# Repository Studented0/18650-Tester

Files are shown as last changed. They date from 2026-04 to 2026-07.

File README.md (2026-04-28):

# CellScan
 
A 4-channel 18650 battery analyzer. Tests up to 4 cells at once and measures voltage, capacity in mAh, and internal resistance per channel. Results show on a small OLED with a rotary encoder to navigate, and a WiFi dashboard to start and stop tests remotely/edit settings.
 
---
 
## Screenshots
 
Schematic
PCB front
PCB back
---
 
## Why I built this
 
My science fair project was a 3S34P battery pack from 34 salvaged 18650 cells. I bought a cheap tester off Amazon to sort them but I wanted to know how it actually worked. I also wanted an excuse to learn PCB design. CellScan is the result, a two-layer PCB with SMD assembly through JLCPCB.
 
---
 
## Hardware
 
Two-layer board, 100×150mm, designed in KiCad 9. SMD components assembled by JLCPCB. Through-hole parts soldered by hand after the board arrives: four MOSFETs, four cement resistors, four cell holders, the OLED header, the ESP32 dev board, and the rotary encoder. The cement resistors run hot under load so they sit raised slightly off the board.
 
Each channel has an INA219 current sensor, an IRLZ44N MOSFET as a discharge switch, and a 1Ω 10W cement resistor as the load. All four INA219s share an I2C bus through a TCA9548A multiplexer since they would otherwise have the same address. Each channel also has a TP4056 lithium charger for charging and discharging. 
 
---
 
## How it measures
 
**Voltage** — INA219 reads bus voltage continuously on each channel.
 
**Capacity** — ESP32 switches the MOSFET on to start discharge. Capacity accumulates by coulomb counting every 500ms until the cell hits the cutoff voltage.
 
`mAh += current_mA * (elapsed_ms / 3600000.0)`
 
**Internal resistance (DCIR)** — Measured at test start using voltage sag. MOSFET off, read open-circuit voltage. MOSFET on, wait 100ms, read loaded voltage and current.
 
`ESR (mΩ) = (V_oc - V_load) / I_load * 1000`
 
---
 
## Rotary Encoder
 
EC11 encoder wired directly to the ESP32. Rotate to switch between channels, press to open a menu, long press to go back. From the menu you can start a test, stop it, or adjust the cutoff voltage per channel. 
 
### Wiring
 
| Signal | GPIO |
|---|---|
| ENC_A | 15 |
| ENC_B | 2 |
| ENC_SW | 5 |
| SDA | 21 |
| SCL | 22 |
 
---
 
## Firmware
 
`firmware/CellScan.ino` — state machine per channel, coulomb counting, DCIR measurement, TP4056 CE control, rotary encoder UI, OLED display, WiFi dashboard.
 
Libraries needed: Adafruit INA219, Adafruit SSD1306, Adafruit GFX, ArduinoJson. Install through Arduino IDE library manager. Board: ESP32 Dev Module.
 
---
 
## Bill of Materials
 
SMD parts ordered through JLCPCB assembly. Through-hole parts sourced separately.
 
| Component | Qty | LCSC | Note |
|---|-----|---|---|
| 100nF 0402 cap | 11 | C1525 | Basic |
| 10kΩ 0402 resistor | 7 | C25744 | Basic |
| 5.1kΩ 0402 resistor | 2 | C25905 | Basic — USB-C CC pull-downs |
| 1.2kΩ 0402 resistor | 4 | C25862 | Extended — TP4056 PROG |
| 1kΩ 0402 resistor | 8 | C11702 | Basic — LED series |
| Red LED 0402 | 8 | C71911 | Extended |
| INA219AIDR | 4 | C138706 | Extended |
| TCA9548AMRGER | 1 | C2876717 | Extended |
| TP4056 SOP-8 | 4 | C16581 | Extended |
| GCT USB4125 USB-C | 1 | C2682777 | Extended |
 
| Component | Qty | Link |
|---|-----|---|
| ESP32 WROOM-32 dev board | 1 | [Amazon](https://www.amazon.com/dp/B08D5ZD528) |
| IRLZ44N MOSFET | 4 | [Amazon](https://www.amazon.com/Technologies-Threshold-Protective-Packaging-IRLZ44NPBF/dp/B0FMQCYG6Q/) |
| 1Ω 10W cement resistor | 4 | [Amazon](https://www.amazon.com/Resistors-Wirewound-Resistance-Precharge-Horizontal/dp/B09V5MTX8Q/) |
| 18650 cell holders | 4 | [Amazon](https://www.amazon.com/Battery-Storage-Holder-Button-Single/dp/B07KD9JLH3/) |
| SSD1306 OLED 0.96" | 1 | [Amazon](https://www.amazon.com/UCTRONICS-SSD1306-Self-Luminous-Display-Raspberry/dp/B072Q2X2LL/) |
| EC11 rotary encoder | 1 | already owned |
 
---
 
## Repository Structure
 
```
18650-Tester/
├── BOM.csv
├── README.md
├── firmware/
│   └── CellScan.ino
└── hardware/
    ├── CellScan_Schematic.kicad_sch
    ├── CellScan_Schematic.kicad_pcb
    ├── CellScan_Schematic.kicad_pro
    ├── CellScan_Schematic.pdf
    ├── libraries/
    │   └── ESP32-DevKitC-30PIN.kicad_mod
    └── gerbers/
```
 
---
 
## License
 
[MIT](LICENSE)

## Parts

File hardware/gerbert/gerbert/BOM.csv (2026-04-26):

Comment | Designator | Footprint | Quantity | LCSC Part | Note
100nF | BAT1.3 BAT1.4 BAT2.3 BAT2.4 BAT3.3 BAT3.4 BAT4.3 BAT4.4 ENCC1 ENCC2 ENCC3 | C_0402_1005Metric | 11 | C1525 | Basic
10k | BAT1.1 BAT2.1 BAT3.1 BAT4.1 ENCR1 ENCR2 ENCR3 | R_0402_1005Metric | 7 | C25744 | Basic
5.1k | R5 R6 | R_0402_1005Metric | 2 | C25905 | Basic — CC1/CC2 USB-C pull-downs
1.2k | BAT1.2 BAT2.2 BAT3.2 BAT4.2 | R_0402_1005Metric | 4 | C25862 | Extended — TP4056 PROG resistors
1k | BAT1RED1 BAT1GREEN1 BAT2RED1 BAT2GREEN1 BAT3RED1 BAT3GREEN1 BAT4RED1 BAT4GREEN1 | R_0402_1005Metric | 8 | C11702 | Basic — LED series resistors
RED LED 0402 | RED1 RED2 RED3 RED4 GREEN1 GREEN2 GREEN3 GREEN4 | LED_0402_1005Metric | 8 | C71911 | Extended — all indicators use same red LED
INA219AIDR | U3 U4 U5 U6 | SOIC-8_3.9x4.9mm_P1.27mm | 4 | C138706 | Extended
TCA9548AMRGER | U2 | Texas_RGE0024C_VQFN-24-1EP_4x4mm_P0.5mm_EP2.1x2.1mm | 1 | C2876717 | Extended
TP4056-42-ESOP8 | U7 U8 U9 U10 | SOIC-8-1EP_3.9x4.9mm_P1.27mm_EP2.41x3.3mm_ThermalVias | 4 | C16581 | Extended
GCT USB4125 USB-C | J3 | USB_C_Receptacle_GCT_USB4125 | 1 | C2682777 | Extended — dedicated 5V power input
-- THROUGH-HOLE (manual solder) --
IRLZ44N MOSFET | Q1 Q2 Q3 Q4 | TO-220-3_Vertical | 4 |  | Amazon — solder by hand
1ohm 10W resistor | R1 R2 R3 R4 | R_Axial_Power_L48.0mm_W12.5mm_P55.88mm | 4 |  | Amazon — solder by hand
18650 cell holder | BT1 BT2 BT3 BT4 | BatteryHolder_Keystone_1042_1x18650 | 4 |  | Amazon — solder by hand
OLED 4-pin header | J1 | PinHeader_1x04_P2.54mm_Vertical | 1 |  | Amazon — solder by hand
ESP32-WROOM-32 dev board | U1 | ESP32-DevKitC-30PIN | 1 |  | Amazon — socket or solder by hand
EC11 rotary encoder | SW1 | RotaryEncoder_Alps_EC11E-Switch_Vertical_H20mm | 1 |  | JLCPCB PCB — solder by hand

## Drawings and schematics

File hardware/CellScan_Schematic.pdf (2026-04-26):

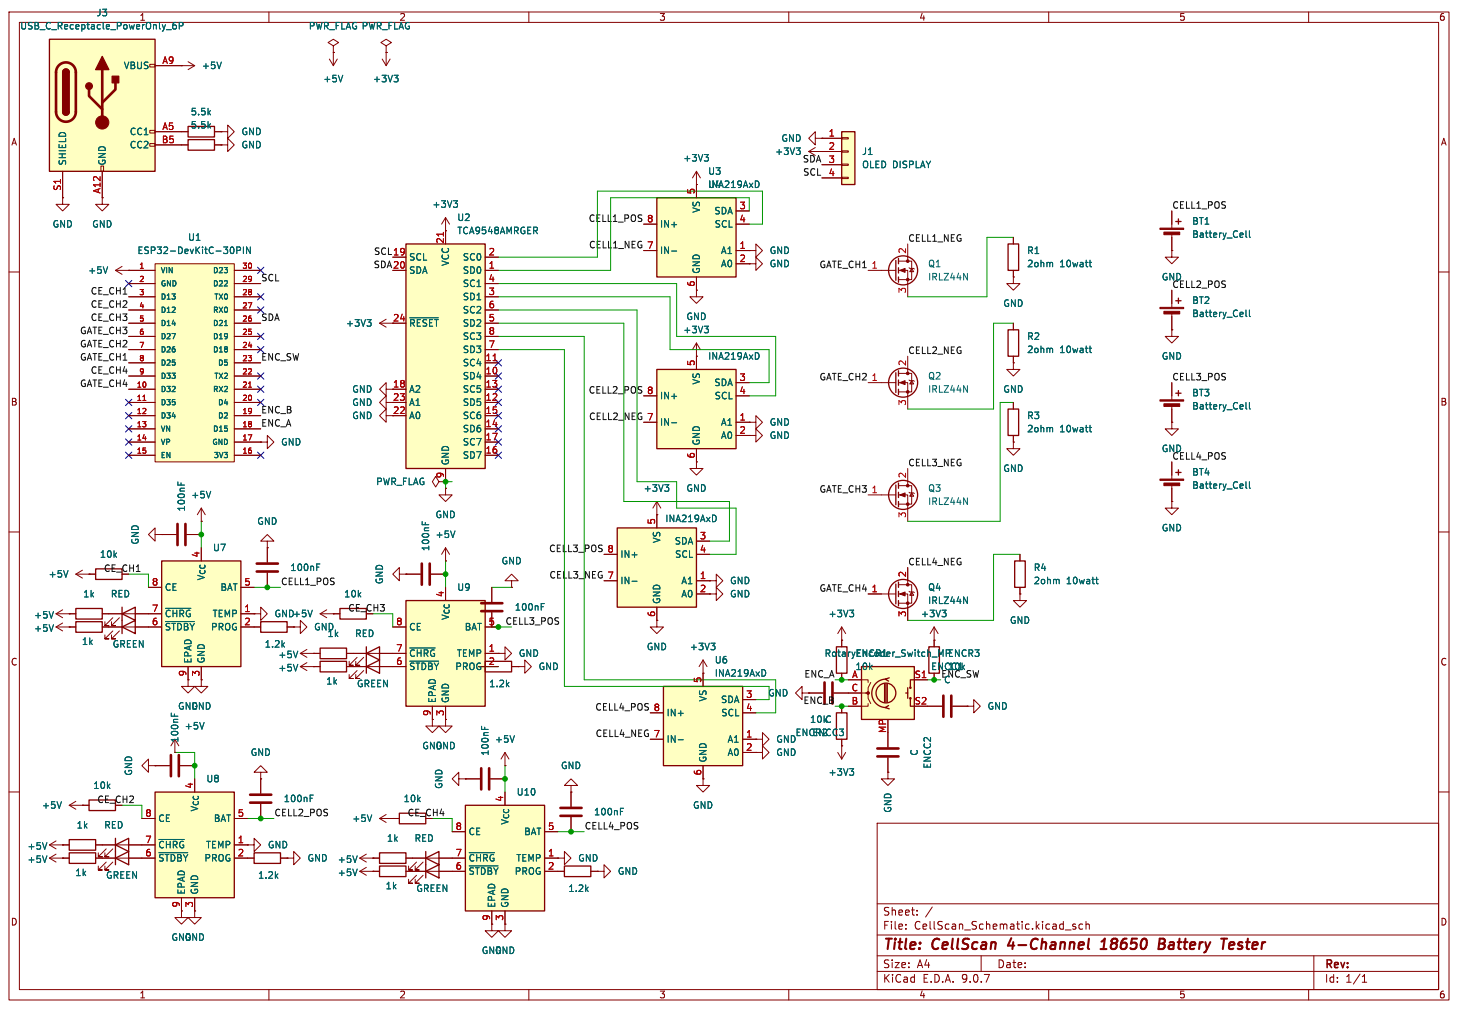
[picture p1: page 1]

6 SDA 3 SCL 4 A1 1 A0 2 GND GND GND

6 SDA 3 SCL 4 A1 1 A0 2 GND GND

3 BAT 5 TEMP 1 PROG 2 U7 RED GREEN GND

6 SDA 3 SCL 4 A1 1 A0 2 GND GND GNDGND

3 BAT 5 TEMP 1 PROG 2 +5V GNDGND GND

3 BAT 5 TEMP 1 PROG 2 U8 GND GND GND

3 BAT 5 TEMP 1 PROG 2 RED

3 BAT 5 TEMP 1 PROG 2 GND 100nF GNDGND

3 BAT 5 TEMP 1 PROG 2 U10 GND GNDGND

3 BAT 5 TEMP 1 PROG 2 RED GND GREEN

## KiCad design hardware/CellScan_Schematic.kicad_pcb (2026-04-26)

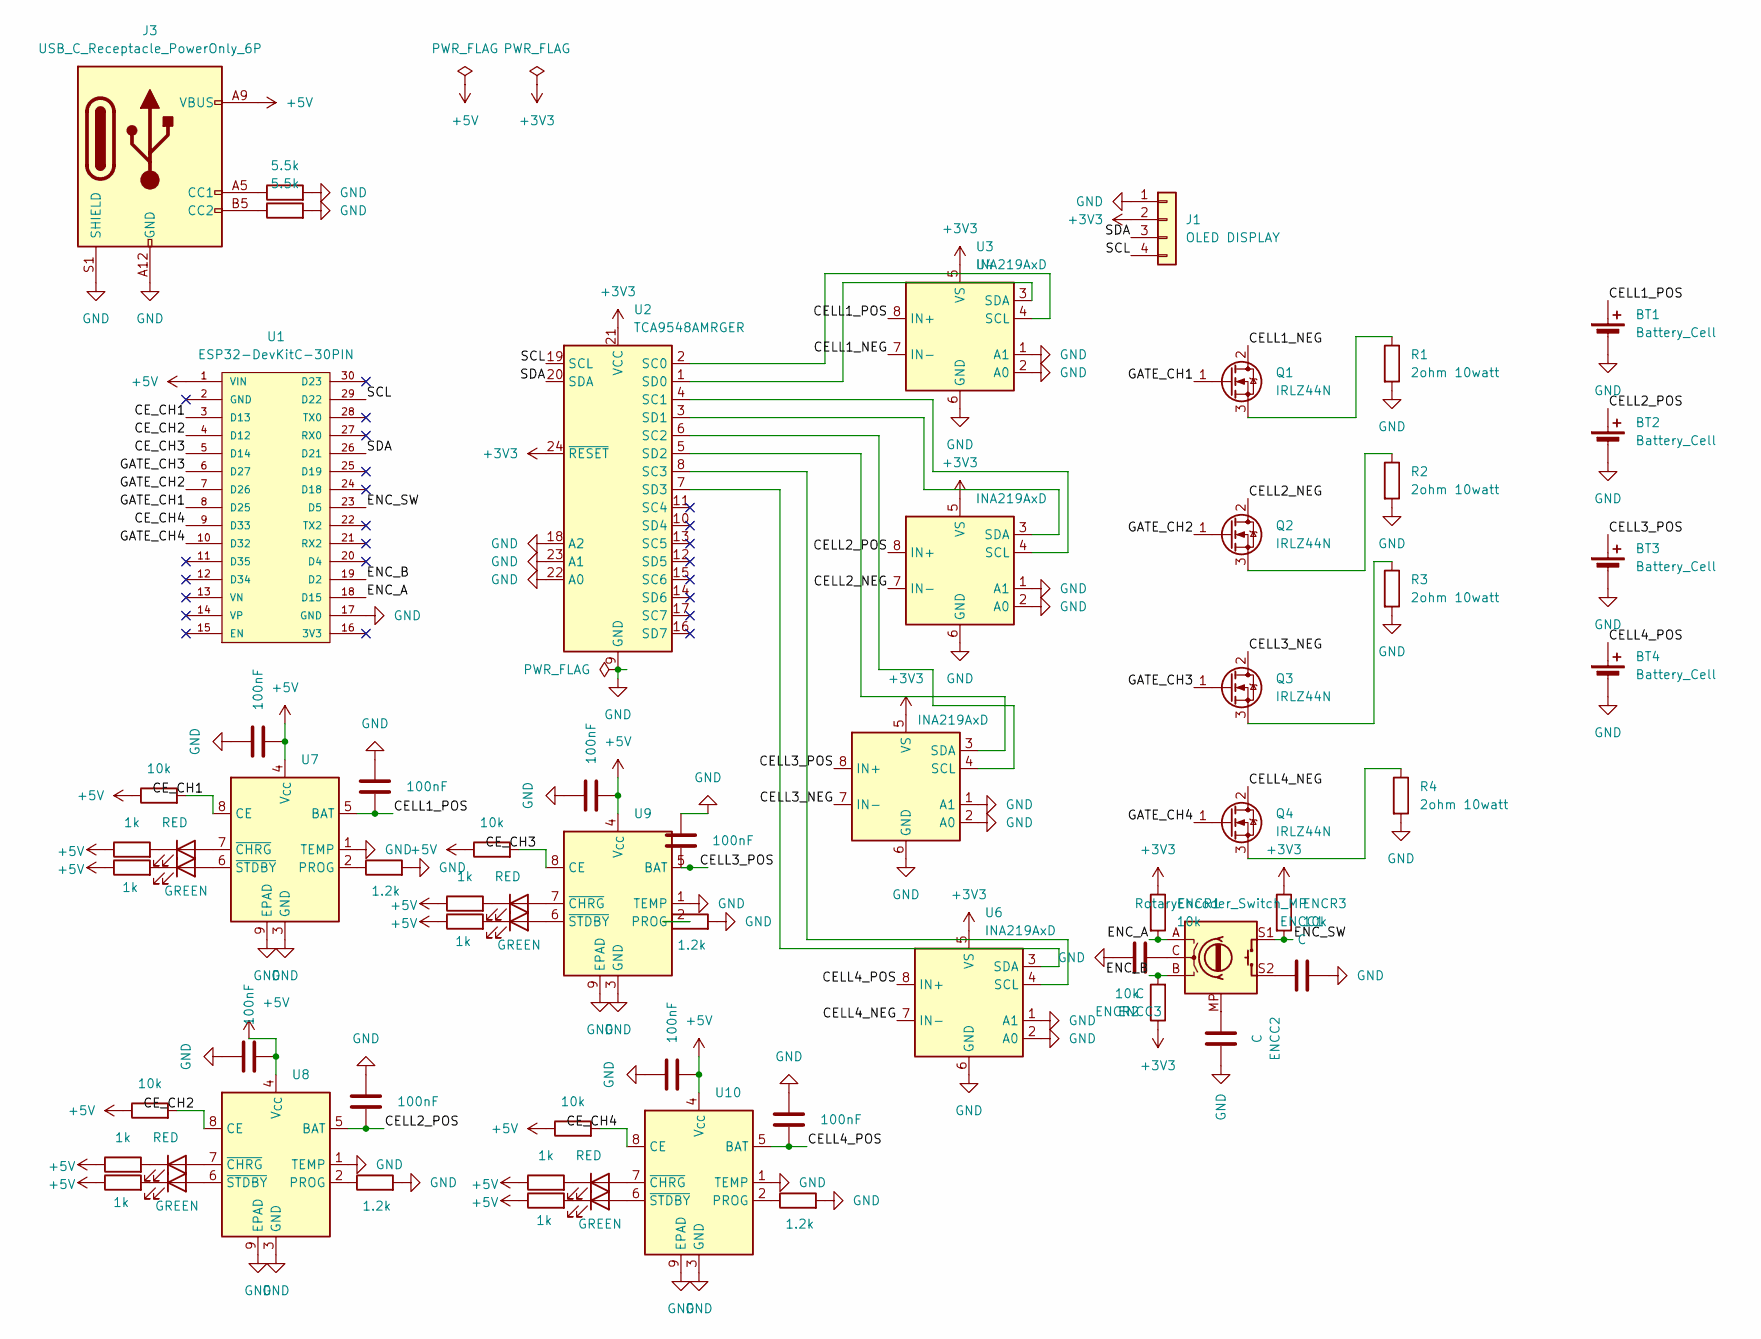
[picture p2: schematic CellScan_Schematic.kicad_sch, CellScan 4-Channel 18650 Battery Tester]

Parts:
BAT1.1, BAT2.1, BAT3.1, BAT4.1: 10k; R_0402_1005Metric
BAT1.2, BAT2.2, BAT3.2, BAT4.2: 1.2k; R_0402_1005Metric
BAT1.3, BAT1.4, BAT2.3, BAT2.4, BAT3.3, BAT3.4, BAT4.3, BAT4.4: 100nF; C_0402_1005Metric
BAT1GREEN1, BAT1RED1, BAT2GREEN1, BAT2RED1, BAT3GREEN1, BAT3RED1, BAT4GREEN1, BAT4RED1: 1k; LED_0402_1005Metric
BT1, BT2, BT3, BT4: Battery_Cell; BatteryHolder_Keystone_1042_1x18650
ENCC1, ENCC2, ENCC3: C; C_0402_1005Metric
ENCR1, ENCR2, ENCR3: 10k; R_0402_1005Metric
GREEN1, GREEN2, GREEN3, GREEN4: GREEN; LED_0402_1005Metric
J1: OLED DISPLAY; PinHeader_1x04_P2.54mm_Vertical
J3: USB_C_Receptacle_PowerOnly_6P; USB_C_Receptacle_GCT_USB4125-xx-x-0190_6P_TopMnt_Horizontal
Q1, Q2, Q3, Q4: IRLZ44N; TO-220-3_Vertical
R1, R2, R3, R4: 2ohm 10watt; R_Axial_Power_L48.0mm_W12.5mm_P55.88mm
R5, R6: 5.5k; R_0402_1005Metric
RED1, RED2, RED3, RED4: RED; LED_0402_1005Metric
SW1: RotaryEncoder_Switch_MP; RotaryEncoder_Alps_EC11E-Switch_Vertical_H20mm
U1: ESP32-DevKitC-30PIN
U2: TCA9548AMRGER; Texas_RGE0024C_VQFN-24-1EP_4x4mm_P0.5mm_EP2.1x2.1mm
U3, U4, U5, U6: INA219AxD; SOIC-8_3.9x4.9mm_P1.27mm
U7, U8, U9, U10: TP4056-42-ESOP8; SOIC-8-1EP_3.9x4.9mm_P1.27mm_EP2.41x3.3mm_ThermalVias

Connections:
+3V3: ENCR1.1, ENCR2.1, ENCR3.1, J1.2, U2.21 (VCC), U2.24 (~RESET), U3.5 (VS), U4.5 (VS), U5.5 (VS), U6.5 (VS)
+5V: BAT1.1.1, BAT1.4.2, BAT1GREEN1.1, BAT1RED1.1, BAT2.1.1, BAT2.4.2, BAT2GREEN1.1, BAT2RED1.1, BAT3.1.1, BAT3.4.2, BAT3GREEN1.1, BAT3RED1.1, BAT4.1.1, BAT4.4.2, BAT4GREEN1.1, BAT4RED1.1, J3.A9 (VBUS), J3.B9 (VBUS), U1.1 (VIN), U7.4 (V_{CC}), U8.4 (V_{CC}), U9.4 (V_{CC}), U10.4 (V_{CC})
/CELL1_NEG: Q1.2 (D), U3.7 (IN-)
/CELL1_POS: BAT1.3.2, BT1.1 (+), U3.8 (IN+), U7.5 (BAT)
/CELL2_NEG: Q2.2 (D), U4.7 (IN-)
/CELL2_POS: BAT2.3.2, BT2.1 (+), U4.8 (IN+), U8.5 (BAT)
/CELL3_NEG: Q3.2 (D), U5.7 (IN-)
/CELL3_POS: BAT4.3.2, BT3.1 (+), U5.8 (IN+), U9.5 (BAT)
/CELL4_NEG: Q4.2 (D), U6.7 (IN-)
/CELL4_POS: BAT3.3.2, BT4.1 (+), U6.8 (IN+), U10.5 (BAT)
/CE_CH1: BAT1.1.2, U1.3 (D13), U7.8 (CE)
/CE_CH2: BAT2.1.2, U1.4 (D12), U8.8 (CE)
/CE_CH3: BAT4.1.2, U1.5 (D14), U9.8 (CE)
/CE_CH4: BAT3.1.2, U1.9 (D33), U10.8 (CE)
/ENC_A: ENCR1.2, SW1.A, U1.18 (D15)
/ENC_B: ENCR2.2, SW1.B, U1.19 (D2)
/ENC_SW: ENCR3.2, SW1.S1, U1.23 (D5)
/GATE_CH1: Q1.1 (G), U1.8 (D25)
/GATE_CH2: Q2.1 (G), U1.7 (D26)
/GATE_CH3: Q3.1 (G), U1.6 (D27)
/GATE_CH4: Q4.1 (G), U1.10 (D32)
/SCL: J1.4, U1.29 (D22), U2.19 (SCL)
/SDA: J1.3, U1.26 (D21), U2.20 (SDA)
GND: BAT1.2.2, BAT1.3.1, BAT1.4.1, BAT2.2.2, BAT2.3.1, BAT2.4.1, BAT3.2.2, BAT3.3.1, BAT3.4.1, BAT4.2.2, BAT4.3.1, BAT4.4.1, BT1.2 (-), BT2.2 (-), BT3.2 (-), BT4.2 (-), ENCC1.2, ENCC2.2, ENCC3.2, J1.1, J3.A12 (GND), J3.B12 (GND), J3.S1 (SHIELD), R1.2, R2.2, R3.2, R4.2, R5.2, R6.2, U1.17 (GND), U2.9 (GND), U2.18 (A2), U2.22 (A0), U2.23 (A1), U3.1 (A1), U3.2 (A0), U3.6 (GND), U4.1 (A1), U4.2 (A0), U4.6 (GND), U5.1 (A1), U5.2 (A0), U5.6 (GND), U6.1 (A1), U6.2 (A0), U6.6 (GND), U7.1 (TEMP), U7.3 (GND), U7.9 (EPAD), U8.1 (TEMP), U8.3 (GND), U8.9 (EPAD), U9.1 (TEMP), U9.3 (GND), U9.9 (EPAD), U10.1 (TEMP), U10.3 (GND), U10.9 (EPAD)
unnamed: ENCC1.1, SW1.S2
unnamed: ENCC2.1, SW1.MP
unnamed: ENCC3.1, SW1.C
unnamed: GREEN1.2 (A), U7.6 (~STDBY)
unnamed: BAT1GREEN1.2, GREEN1.1 (K)
unnamed: GREEN2.2 (A), U8.6 (~STDBY)
unnamed: BAT2GREEN1.2, GREEN2.1 (K)
unnamed: GREEN3.2 (A), U9.6 (~STDBY)
unnamed: BAT4RED1.2, GREEN3.1 (K)
unnamed: GREEN4.2 (A), U10.6 (~STDBY)
unnamed: BAT3GREEN1.2, GREEN4.1 (K)
unnamed: J3.A5 (CC1), R5.1
unnamed: J3.B5 (CC2), R6.1
unnamed: Q1.3 (S), R1.1
unnamed: Q2.3 (S), R2.1
unnamed: Q3.3 (S), R3.1
unnamed: Q4.3 (S), R4.1
unnamed: RED1.2 (A), U7.7 (~CHRG)
unnamed: BAT1RED1.2, RED1.1 (K)
unnamed: RED2.2 (A), U8.7 (~CHRG)
unnamed: BAT2RED1.2, RED2.1 (K)
unnamed: RED3.2 (A), U9.7 (~CHRG)
unnamed: BAT4GREEN1.2, RED3.1 (K)
unnamed: RED4.2 (A), U10.7 (~CHRG)
unnamed: BAT3RED1.2, RED4.1 (K)
unnamed: U2.2 (SC0), U3.4 (SCL)
unnamed: U2.4 (SC1), U4.4 (SCL)
unnamed: U2.6 (SC2), U5.4 (SCL)
unnamed: U2.8 (SC3), U6.4 (SCL)
unnamed: U2.1 (SD0), U3.3 (SDA)
unnamed: U2.3 (SD1), U4.3 (SDA)
unnamed: U2.5 (SD2), U5.3 (SDA)
unnamed: U2.7 (SD3), U6.3 (SDA)
unnamed: BAT1.2.1, U7.2 (PROG)
unnamed: BAT2.2.1, U8.2 (PROG)
unnamed: BAT4.2.1, U9.2 (PROG)
unnamed: BAT3.2.1, U10.2 (PROG)

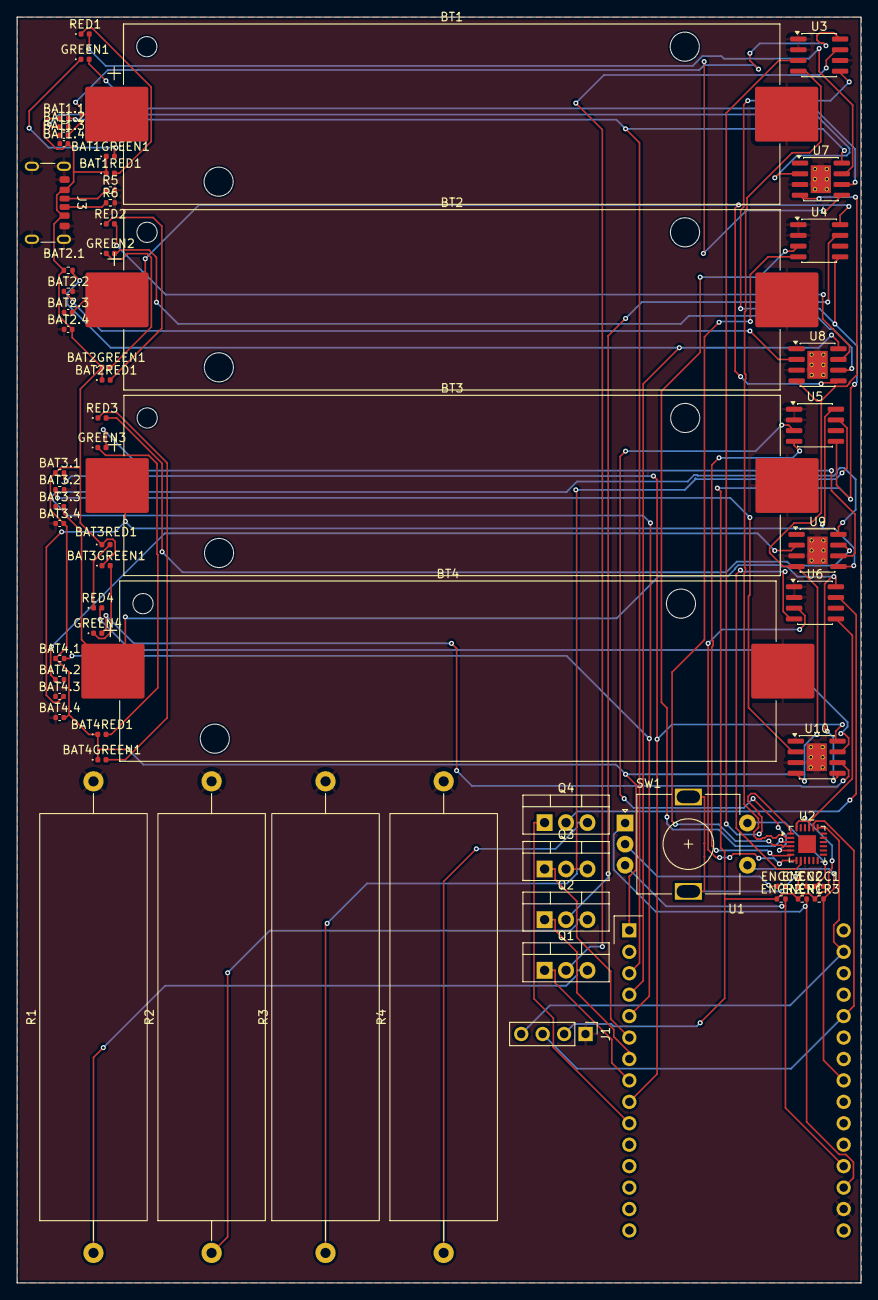
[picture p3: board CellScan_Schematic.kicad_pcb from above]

Board: 2 copper layers, 100.0 x 150.0 mm, 65 parts (0 on the bottom side), 61 nets.

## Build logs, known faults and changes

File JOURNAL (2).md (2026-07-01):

<!--
  This journal is auto generated by Stasis.
-->

# 4/26/2026 4 AM - GitHub & JLCPCB Submission

_Time spent: 1.5h_

Pushed everything to GitHub, schematic, PCB, gerbers, firmware, BOM, CPL, and the custom ESP32 footprint library. Cleaned up the repo structure and rewrote the README with the full GPIO map, assembly instructions, and updated BOM table.
Uploaded the gerbers to JLCPCB and went through parts matching. Most parts matched automatically from the previous session. The USB4125 connector had been matched to a 24MHz crystal oscillator which was completely wrong, searched for USB4125 manually and switched to C5246813 which is the correct GCT USB4125-GF-A-0190. That one added about $4 to the total because it's an Extended part with a $3 sourcing fee on top of the part cost.
Verified every part; all 0402 footprints confirmed, LED polarity noted, IC packages checked.
Final order: 5 PCBs, 2 assembled, black soldermask, HASL with lead, Global Standard shipping. Grand total $62.51 after a $9 coupon. 




# 4/26/2026 4 AM - PCB Design

_Time spent: 8h_

Before touching the PCB layout I reviewed the schematic and found two bugs that would have made the board non-functional. All four MOSFETs had Gate and Drain swapped, the GATE_CHx nets were on the Drain pins, meaning the ESP32 would have driven the wrong terminal entirely. Also had GATE_CH4 on IO14 instead of IO32, and IO14 is a strapping pin. Fixed both before doing anything else.
The ESP32 footprint took about two hours. I was using the WROOM-32 module symbol which numbers pins by the chip's castellated pads, not the dev board header row. Any header footprint assigned to it would route completely wrong nets to wrong holes. Was spending too much time trying to find a replacement so I built a custom symbol and footprint from scratch two rows of 15 pins, 2.54mm pitch, 25.4mm row spacing.
I wanted to add charging to the system so I added TP4056 charging circuits per channel, a dedicated USB-C power input separate from the programming port, and then I also decided to add a rotary encoder for standalone OLED navigation without needing WiFi.
FreeRouting ran three times total. First had display artifacts showing false unrouted connections. Second had 34 unrouted because the ESP32 was placed flipped. Third resolved clean after 21+ passes.
Biggest DRC issue was TP4056 EPAD thermal vias defaulting to 0.2mm drill, JLCPCB minimum is 0.3mm. The scripting console kept throwing errors on multiline code so I fixed all 24 vias by hand across four footprints. Parts matching on JLCPCB also caught LED footprint mismatches before ordering, auto-matched 0603 parts to 0402 pads.
 Also wrote the firmware for the encoder, rotate to switch between channels on the OLED, press to open a menu, long press to go back. From the menu you can start a test, stop it, or set the cutoff voltage per channel. 
CellScan_Schematic

CellScan_Schematic2




# 4/26/2026 4 AM - Breadboard Prototype

_Time spent: 7h_

Getting the ESP32 recognized took longer than expected. The board was plugged in but nothing showed up in the Arduino IDE, and Device Manager. Turned out I needed to download a driver for it to work; once that was installed COM13 appeared and I could compile. First compile took a few minutes because the entire ESP32 core builds from scratch the first time, thought it had frozen.
Ran an I2C scan first. OLED showed up at 0x3C immediately. INA219 didn't show up at all. My first thought was to try it without soldering the headers just press the pins into the breadboard and see if it makes contact. It didn't. No amount of pressing got a consistent connection. Ended up soldering the headers properly and running the scan again, and both addresses appeared.
Before wiring any cells I tested the MOSFET and INA219 with a simple LED, gate high, LED on, gate low, LED off. Confirmed the switch worked and the sensor was reading correctly. Then wired up the full discharge path and ran the first real test.
MOSFET overheated mid-test. Touched it and it burned my finger (im good it wasnt a bad burn). Grabbed the laser thermometer; 160°F. Unplugged immediately. Turned out the gate pin wasn't fully seated in the breadboard so the device was running in its linear region instead of switching cleanly. Pushed it all the way in and temperature dropped to 105°F.  Gate wire also came loose mid-discharge once and killed the current reading entirely.
Once I had a charged cell the discharge loop ran correctly; voltage holding in the flat plateau, capacity counting up steadily. 

(You can see another project I finished for stasis; PiMusic)











# 4/14/2026 3 AM - Firmware

_Time spent: 4h_

Wrote all the firmware for Cellscan in Arduino IDE.Set up the ESP32 with a state machine per channel: IDLE, DCIR measurement, discharging, done. DCIR is measured at test start by reading open circuit voltage, then switching the MOSFET on, waiting 100ms, and measuring the voltage sag divided by current. Capacity accumulates every 500ms using coulomb counting. OLED rotates through all 4 channels every 3 seconds (will adjust to liking). WiFi hosts a dashboard at the ESP32's IP with live readings and start/stop buttons per channel. Hit a compile error first try: backticks in the JavaScript inside the HTML string aren't valid C++. Rewrote the HTML builder using string concatenation. Compiled clean on ESP32 Dev Module. Pushed firmware to repo, cleaned up the README, added 

LICENSE.





# 3/5/2026 11 PM - Finishing up Schematic

_Time spent: 1.75h_

Finished the KiCad schematic for CellScan. Added PWR_FLAG symbols for KiCad to clear power net ERC issues then ran the ERC and got 0 flags. Updated the repo to have the schematic and the README to have the schematic







# 3/5/2026 10 AM - Schematic

_Time spent: 0.75h_

Started working on the schematic for the wiring of the full system. Design is not yet done. Ran into some issues and honestly was a little burnt out from working on this project for around 5ish hours straight without a break. Will take a break and get back to it later. Wiring is just mixed up.







# 3/5/2026 9 AM - Background research

_Time spent: 3.75h_

I decided to build a 18650 cell tester. I got this idea from my science fair project. I built a 3S34P battery pack from recycled 18650 cells. Testing each individual battery sucks and requires a tester. I purchased one from amazon but I want to learn how it works myself, so I decided to build one on my own. I decided on 4 channels because that's what I used and you could test one row of series at once. Each channel would measure voltage, capacity, and internal resistance. For sensing, I landed on the INA219. It measures both voltage and current over I2C, which keeps the wiring simple. One problem is that INA219s have the same default I2C address, so I'm also getting a TCA9548A I2C multiplexer to fix that issue. Each channel would also need a MOSFET and a load resistor to do controlled discharge. The capacity is measured by measuring current continuously during discharge and adding up (current x time) until the cell hits the voltage cutoff, which would be adjustable by the web app. Internal resistance would be measured at the very start by voltage sag. Apply load, measure how much voltage sags, and divide by the current. Results would go on an OLED screen and the WiFi dashboard that an ESP32 would host. Set up the GitHub repo and wrote some of the README. Did some research on the parts needed 
(session was closer to 4 and half hours but I could not upload video explaining what I worked on)
Screenshot 2026-03-05 030120 - Copy

Screenshot 2026-03-05 030135 - Copy

Screenshot 2026-03-05 030204 - Copy





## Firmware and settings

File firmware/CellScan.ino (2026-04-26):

/*
 * CellScan — 4-Channel 18650 Battery Analyzer
 * ESP32 + TCA9548A + 4x INA219 + IRLZ44N + 4x TP4056 + EC11 + SSD1306
 *
 * Pin map:
 *   SDA       = GPIO21   SCL       = GPIO22
 *   GATE_CH1  = GPIO25   GATE_CH2  = GPIO26
 *   GATE_CH3  = GPIO27   GATE_CH4  = GPIO32
 *   CE_CH1    = GPIO13   CE_CH2    = GPIO12  (see boot note below)
 *   CE_CH3    = GPIO14   CE_CH4    = GPIO33
 *   ENC_A     = GPIO15   ENC_B     = GPIO2   ENC_SW = GPIO5
 *
 * HARDWARE NOTE — GPIO12 (CE_CH2):
 *   GPIO12 is a strapping pin. High at boot selects 1.8V flash mode,
 *   which causes boot failures on standard 3.3V flash modules.
 *   Burn EFLASH if needed
 *
 *
 * ENCODER UI:
 *   Rotate       = navigate channels / menu items / adjust values
 *   Short press  = select / confirm
 *   Long press   = back / cancel
 */

#include <Wire.h>
#include <WiFi.h>
#include <WebServer.h>
#include <Adafruit_INA219.h>
#include <Adafruit_SSD1306.h>
#include <Adafruit_GFX.h>
#include <ArduinoJson.h>

const char* WIFI_SSID     = "YOUR_SSID";
const char* WIFI_PASSWORD = "YOUR_PASSWORD";

#define TCA_ADDR     0x70
#define INA219_ADDR  0x40
#define NUM_CH       4
#define OLED_W       128
#define OLED_H       64
#define OLED_RST     -1

const int MOSFET_PINS[NUM_CH] = {25, 26, 27, 32};
const int CE_PINS[NUM_CH]     = {13, 12, 14, 33};

#define ENC_A   15
#define ENC_B   2
#define ENC_SW  5

#define CUTOFF_DEF   2.80f
#define CUTOFF_MIN   2.50f
#define CUTOFF_MAX   3.20f
#define CUTOFF_STEP  0.05f
#define POLL_MS      500
#define DCIR_MS      100

// ---------- Channel state ----------
enum ChanState { ST_IDLE, ST_DCIR, ST_DSG, ST_DONE, ST_ERR };

struct Channel {
  ChanState state     = ST_IDLE;
  float     v         = 0;
  float     i_ma      = 0;
  float     mah       = 0;
  float     esr       = 0;
  float     voc       = 0;
  float     cutoff    = CUTOFF_DEF;
  uint32_t  last_ms   = 0;
};

Channel ch[NUM_CH];

// ---------- UI state ----------
enum Screen { SCR_CHAN, SCR_MENU, SCR_CUTOFF };

Screen  scr       = SCR_CHAN;
int     sel_ch    = 0;
int     sel_item  = 0;
float   edit_val  = 0;

const char* ITEMS[] = {"Start Test", "Stop Test", "Set Cutoff", "Back"};
const int   N_ITEMS = 4;

// ---------- Encoder ----------
volatile int enc_delta = 0;
void IRAM_ATTR enc_isr() {
  if (digitalRead(ENC_B)) enc_delta++;
  else                     enc_delta--;
}

uint32_t btn_ms   = 0;
bool     btn_down = false;
bool     ev_sp    = false;
bool     ev_lp    = false;

void poll_btn() {
  bool d = (digitalRead(ENC_SW) == LOW);
  if (d && !btn_down) { btn_ms = millis(); btn_down = true; }
  else if (!d && btn_down) {
    btn_down = false;
    if (millis() - btn_ms >= 500) ev_lp = true;
    else                          ev_sp = true;
  }
}

// ---------- Peripherals ----------
Adafruit_INA219  ina(INA219_ADDR);
Adafruit_SSD1306 oled(OLED_W, OLED_H, &Wire, OLED_RST);
WebServer        srv(80);

// ---------- Hardware helpers ----------
void tca(uint8_t c) {
  Wire.beginTransmission(TCA_ADDR);
  Wire.write(1 << c);
  Wire.endTransmission();
}

void gate_on(int c)  { digitalWrite(MOSFET_PINS[c], HIGH); }
void gate_off(int c) { digitalWrite(MOSFET_PINS[c], LOW);  }

void ce_off(int c) { pinMode(CE_PINS[c], OUTPUT); digitalWrite(CE_PINS[c], LOW); }
void ce_on(int c)  { pinMode(CE_PINS[c], INPUT); }  // pull-up brings CE high

bool ina_read(int c, float &v, float &i_ma) {
  tca(c);
  delayMicroseconds(200);
  float bv = ina.getBusVoltage_V();
  float sv = ina.getShuntVoltage_mV();
  v    = bv + sv / 1000.0f;
  i_ma = ina.getCurrent_mA();
  return !(v < 0.5f && fabsf(i_ma) < 1.0f);
}

const char* st_str(ChanState s) {
  switch (s) {
    case ST_IDLE: return "IDLE"; case ST_DCIR: return "DCIR";
    case ST_DSG:  return "DSG "; case ST_DONE: return "DONE";
    case ST_ERR:  return "ERR "; default:       return "????";
  }
}

// ---------- Test control ----------
void start_test(int c) {
  float v, i_ma;
  if (!ina_read(c, v, i_ma) || v < 2.5f) { ch[c].state = ST_ERR; return; }
  ce_off(c);
  delay(200);
  ch[c].state = ST_DCIR;
  ina_read(c, ch[c].voc, i_ma);
  gate_on(c);
  delay(DCIR_MS);
  float vl, il;
  ina_read(c, vl, il);
  if (il > 1.0f) ch[c].esr = ((ch[c].voc - vl) / (il / 1000.0f)) * 1000.0f;
  ch[c].state   = ST_DSG;
  ch[c].mah     = 0;
  ch[c].last_ms = millis();
}

void stop_test(int c) {
  gate_off(c);
  ce_on(c);
  ch[c].state = ST_IDLE;
}

void update_ch(int c) {
  if (ch[c].state != ST_DSG) return;
  uint32_t now = millis();
  if (now - ch[c].last_ms < POLL_MS) return;
  float v, i_ma;
  if (!ina_read(c, v, i_ma)) { stop_test(c); ch[c].state = ST_ERR; return; }
  ch[c].v    = v;
  ch[c].i_ma = i_ma;
  ch[c].mah += i_ma * (float)(now - ch[c].last_ms) / 3600000.0f;
  ch[c].last_ms = now;
  if (v <= ch[c].cutoff) { gate_off(c); ce_on(c); ch[c].state = ST_DONE; }
}

// ---------- UI logic ----------
void menu_act(int item) {
  switch (item) {
    case 0:
      if (ch[sel_ch].state == ST_IDLE || ch[sel_ch].state == ST_DONE)
        start_test(sel_ch);
      scr = SCR_CHAN; break;
    case 1: stop_test(sel_ch); scr = SCR_CHAN; break;
    case 2: edit_val = ch[sel_ch].cutoff; scr = SCR_CUTOFF; break;
    case 3: scr = SCR_CHAN; break;
  }
}

void handle_ui() {
  poll_btn();
  int d  = enc_delta; enc_delta = 0;
  bool sp = ev_sp; ev_sp = false;
  bool lp = ev_lp; ev_lp = false;

  switch (scr) {
    case SCR_CHAN:
      if (d)  sel_ch = (sel_ch + d + NUM_CH) % NUM_CH;
      if (sp) { sel_item = 0; scr = SCR_MENU; }
      break;
    case SCR_MENU:
      if (d)  sel_item = (sel_item + d + N_ITEMS) % N_ITEMS;
      if (sp) menu_act(sel_item);
      if (lp) scr = SCR_CHAN;
      break;
    case SCR_CUTOFF:
      if (d)  edit_val = constrain(edit_val + d * CUTOFF_STEP, CUTOFF_MIN, CUTOFF_MAX);
      if (sp) { ch[sel_ch].cutoff = edit_val; scr = SCR_MENU; }
      if (lp) scr = SCR_MENU;
      break;
  }
}

// ---------- OLED ----------
void draw_chan() {
  Channel &c = ch[sel_ch];
  oled.clearDisplay();
  oled.setTextColor(SSD1306_WHITE);
  oled.setTextSize(1);
  oled.setCursor(0, 0);
  oled.printf("CELL%d  [%s]", sel_ch + 1, st_str(c.state));
  oled.drawLine(0, 9, 127, 9, SSD1306_WHITE);
  oled.setCursor(0, 12); oled.printf("V:   %.3f V",   c.v);
  oled.setCursor(0, 21); oled.printf("I:   %.0f mA",  c.i_ma);
  oled.setCursor(0, 30); oled.printf("Cap: %.1f mAh", c.mah);
  oled.setCursor(0, 39); oled.printf("ESR: %.0f mO",  c.esr);
  oled.drawLine(0, 51, 127, 51, SSD1306_WHITE);
  oled.setCursor(0, 54);
  if (WiFi.status() == WL_CONNECTED) oled.print(WiFi.localIP().toString());
  else oled.printf("Cut:%.2fV  Press=menu", c.cutoff);
  oled.display();
}
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

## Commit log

2026-03-05 Revise README for CellScan 18650 Battery Analyzer
    Updated project name and expanded README with detailed features, measurements, wiring diagram, bill of materials, firmware details, and repository structure.
2026-03-05 Add files via upload
    unfinished version of main schematic
    [CellScan_Schematic.kicad_sch]
2026-03-05 Revise Bill of Materials and update total cost
    Updated bill of materials and total cost.
2026-04-14 Fix schematic link in README
    Updated the link for the CellScan schematic in the README.
2026-04-26 Updated Firmware for PCB
2026-04-26 Gerber files and BOM and whatnot
2026-04-26 Revise README for clarity and additional details
    Updated project description, system architecture, and wiring diagram. Enhanced explanations for measurements and added details about firmware and assembly.
2026-04-26 Update README with assembly images and details
    Added images to the README for assembly and hardware details.
